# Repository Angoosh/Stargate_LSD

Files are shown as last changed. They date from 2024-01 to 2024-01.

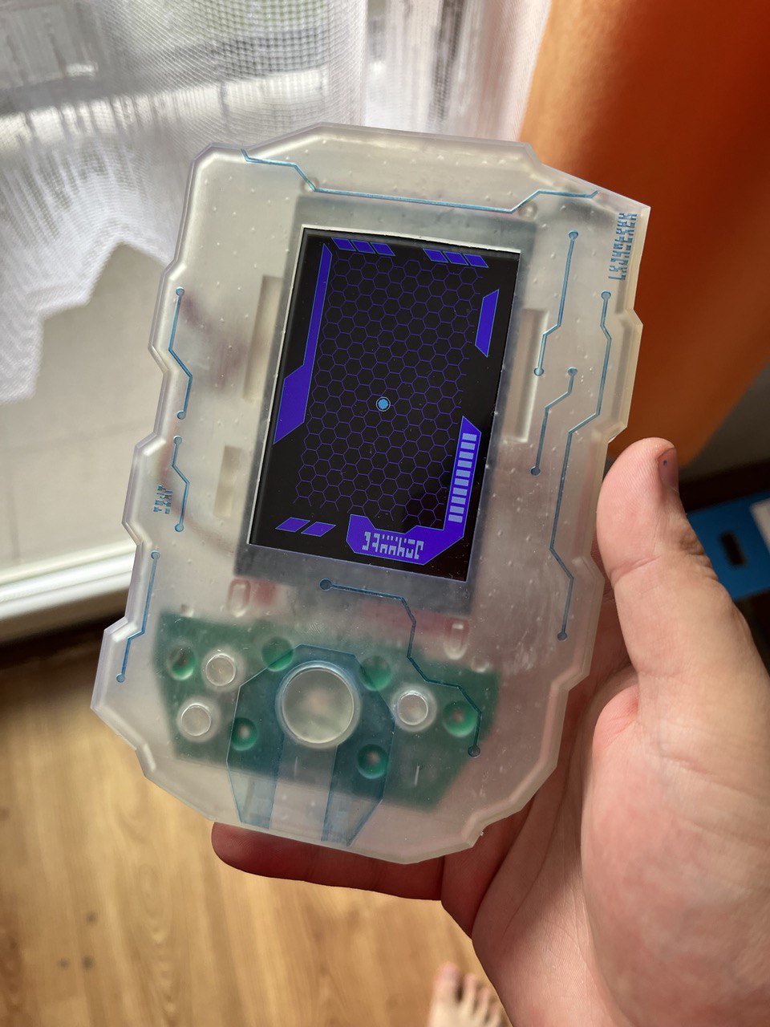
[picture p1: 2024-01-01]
image.jpg

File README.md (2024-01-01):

# Stargate_LSD
A Stargate Atlantis lifesigns detector prop design files and software. This is not a 1:1 prop replica, because I couldn't find screen which would match, but it is close enough. It was originally made as a reaction to one of my friends suggestions that we need a dork particle detector or as in our czech language kokoton detektor.

## Case printing and painting:
Case is printed out on a Elegoo Mars 2 Pro resin printer with Phrozen aqua clear resin. Painting is done with diluted transparent blue enamel paint and sanded over.

## Electronics:
Mainboard: [[https://github.com/LaskaKit/ESPD-35/tree/main]] but anything should fit with 3d model change. It is based on ESP32 because I wanted simplicity of arduino and wireless capabilities for future functions.<br>
Buttons use my custom PCB made with KiCAD.<br>
For sensors: SHT40 and VL53L0X are used.<br>
Optional other sensors and stuff can be programmed in and connected via pin header in the bottom of the device.

## Software:
It is a mess made on long nights over a 4 month period. It contains 3 modes in which it can operate:<br>
Dork particle detector, which uses the ToF sensor.<br
A temperature and humidity monitor.<br>
And as a life signs detector which is WIP and I don't know when it will be finished with all features. Right now it is just a simple blinking and beeping dot in the middle of the screen, but I have an idea to make it into a "real" life signs detector with an array of stationary beacons scattered around an area where it should detect stuff which will triangulate positions of the LSD and other mobile beacons and send that data into the LSD over MQTT or something like that. I don't know when I will have the time and mood to do that. Probably when the need arises for some LARP or something.

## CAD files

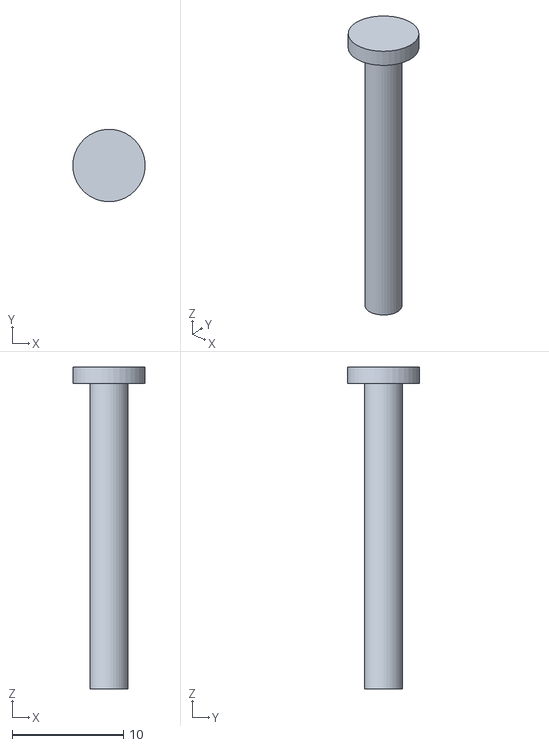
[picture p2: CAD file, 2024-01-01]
Hardware/3D print/power_button.STL
6.52 x 6.52 x 29.0

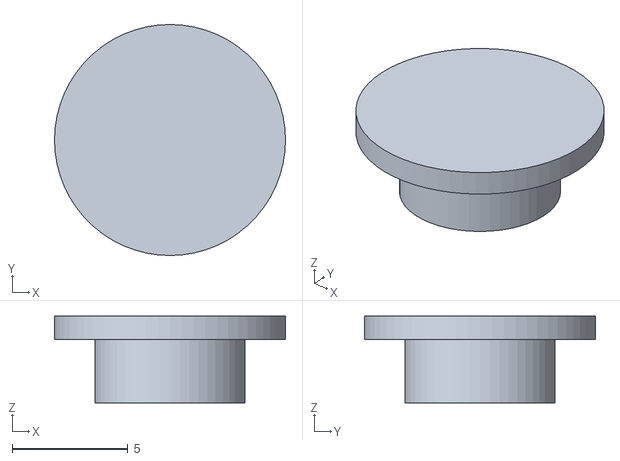
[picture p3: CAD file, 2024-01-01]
Hardware/3D print/tlacitko_male.STL
10.00 x 10.00 x 3.75

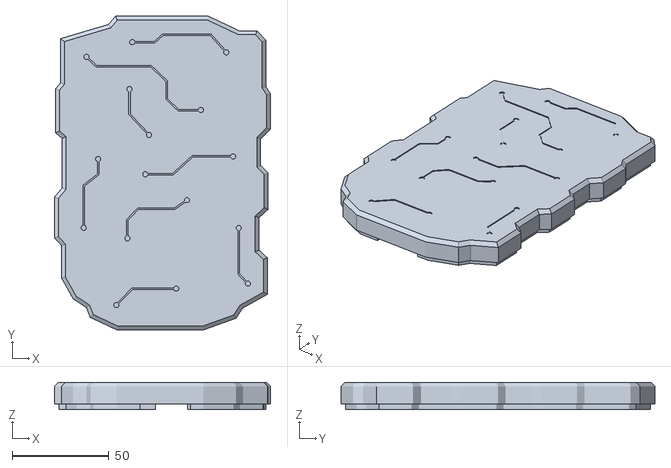
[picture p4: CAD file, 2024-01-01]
Hardware/3D print/Case_back.STL
111.4 x 161.9 x 14.0

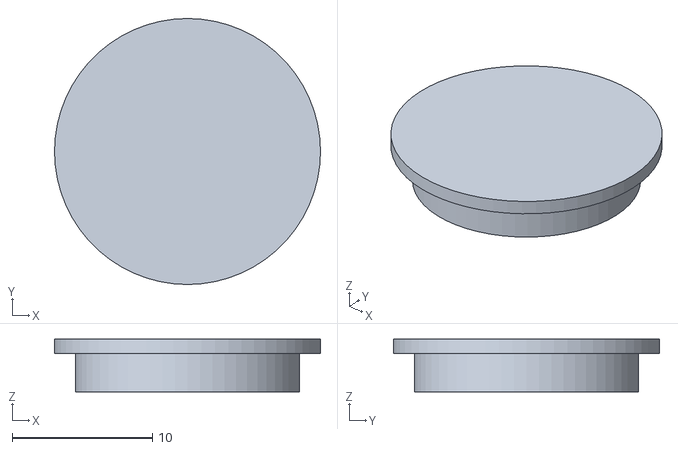
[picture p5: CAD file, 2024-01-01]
Hardware/3D print/tlacitko_velke.STL
19.0 x 19.0 x 3.75

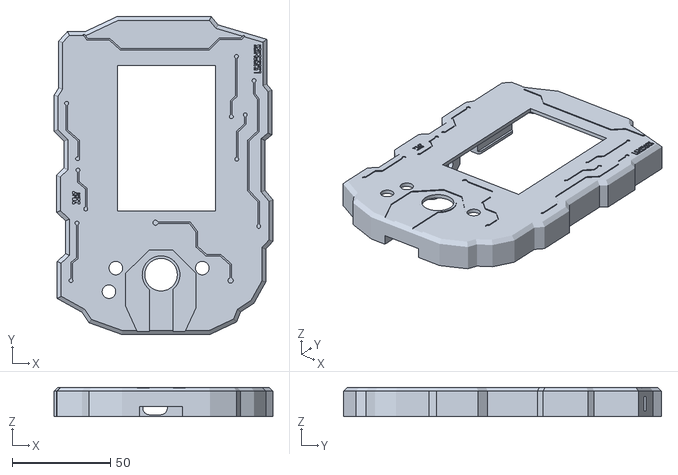
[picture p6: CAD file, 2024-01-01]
Hardware/3D print/Case_front.STL
111.4 x 161.9 x 15.0

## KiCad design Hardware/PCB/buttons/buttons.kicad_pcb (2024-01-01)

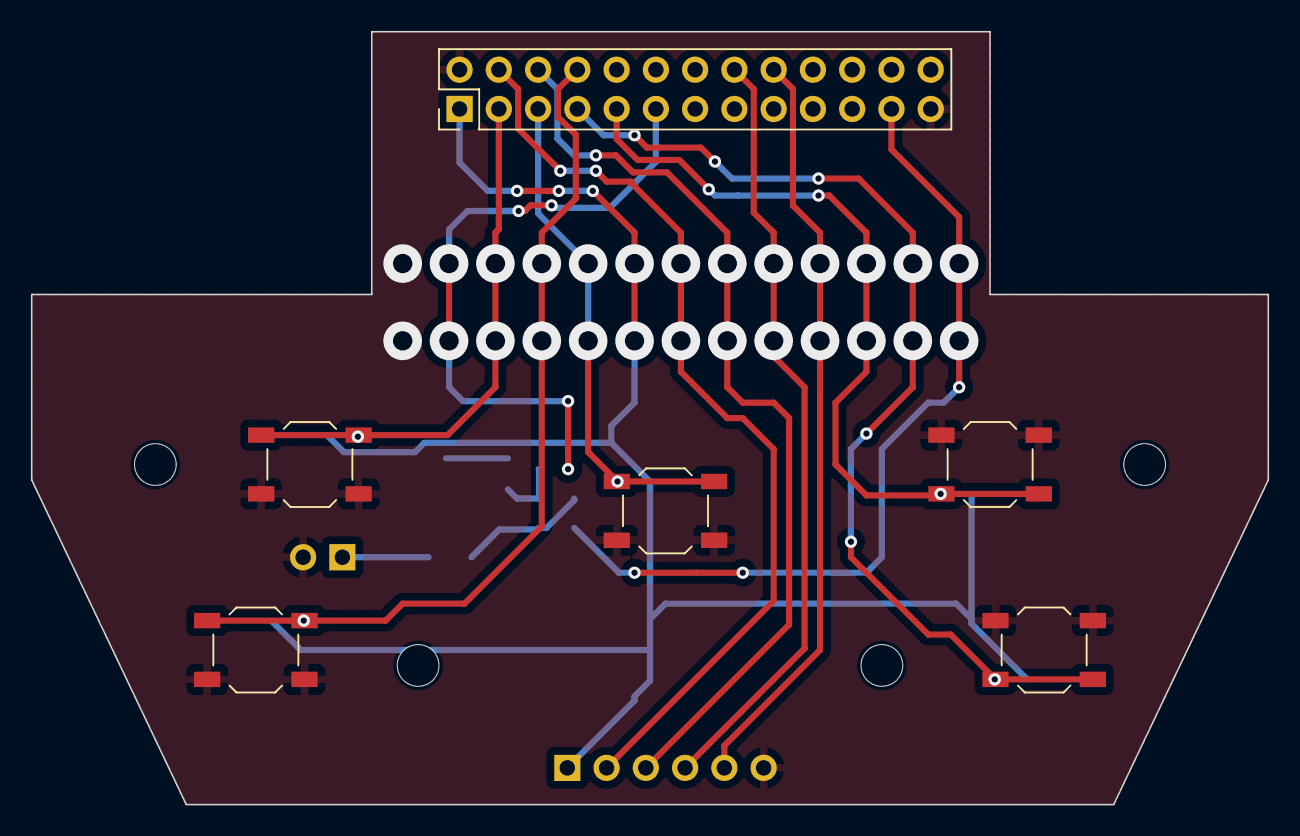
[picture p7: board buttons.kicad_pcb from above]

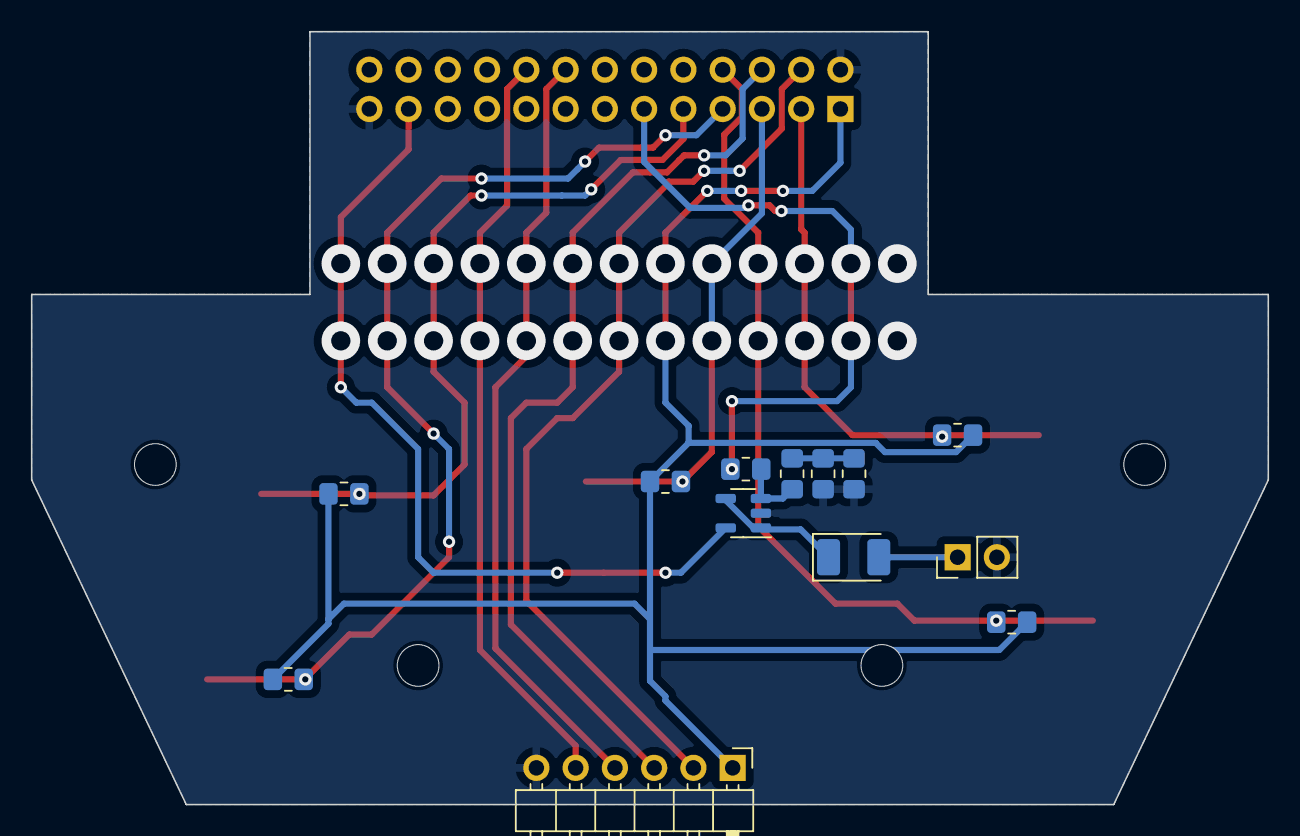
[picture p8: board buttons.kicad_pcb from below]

Board: 2 copper layers, 80.0 x 50.0 mm, 19 parts (13 on the bottom side), 17 nets.

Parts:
C1: 47u; CP_EIA-3528-21_Kemet-B_Pad1.50x2.35mm_HandSolder
J1: Conn_02x13_Odd_Even; PinHeader_2x13_P2.54mm_Vertical
J2: Conn_01x06; PinHeader_1x06_P2.54mm_Horizontal
LS1: Speaker; PinHeader_1x02_P2.54mm_Vertical
R1, R2, R3, R4: 10k; R_0805_2012Metric_Pad1.20x1.40mm_HandSolder
R5, R6, R7, R8, R9: 4k7; R_0805_2012Metric_Pad1.20x1.40mm_HandSolder
SW1, SW2, SW3, SW4, SW5: SW_Push; SW_SPST_TL3342
U1: AD8531ARTZ; SOT-23-5

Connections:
+3V3: J1.1, J2.1, R5.1, R6.1, R7.1, R8.1, R9.1
+BATT: J1.23, U1.5 (V+)
/SCL: J1.18, J2.5
/SDA: J1.16, J2.4
/SOUND: J1.11, R1.2
/SW_BACK: J1.7, R9.2, SW5.2
/SW_CENT: J1.5, R7.2, SW3.1
/SW_DWN: J1.8, R5.2, SW2.1
/SW_MENU: J1.9, R8.2, SW4.2
/SW_RX: J1.4, J2.2
/SW_TX: J1.6, J2.3
/SW_UP: J1.3, R6.2, SW1.1
GND: J1.2, J1.25, J2.6, LS1.2, R3.2, R4.2, SW1.2, SW2.2, SW3.2, SW4.1, SW5.1, U1.2 (V-)
unnamed: C1.2, LS1.1
unnamed: R2.2, R3.1, R4.1
unnamed: R1.1, R2.1, U1.3 (+)
unnamed: C1.1, U1.1, U1.4 (-)

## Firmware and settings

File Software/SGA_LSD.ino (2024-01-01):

#include <TFT_eSPI.h>            // Hardware-specific library
#include <SPI.h>
#include <Arduino.h>
#include <FS.h>
#include <ESP32AnalogRead.h>
#include "Wire.h"
#include "Adafruit_VL53L0X.h"
#include "Adafruit_SHT4x.h"
#include "SoundData.h"
#include "XT_DAC_Audio.h"

// TFT resolution
#define TFT_DISPLAY_RESOLUTION_X  320
#define TFT_DISPLAY_RESOLUTION_Y  480
#define CENTRE_Y                  TFT_DISPLAY_RESOLUTION_Y/2

// TFT SPI
#define TFT_LED          33      // TFT backlight pin
#define TFT_LED_PWM      100     // dutyCycle 0-255 last minimum was 15

// Buttons
#define BUTTON_UP        36
#define BUTTON_DOWN      16
//#define BUTTON_BACK      34
#define BUTTON_MENU      35
#define BUTTON_CENTER    39

//font
#define ALTERAN "stargate-alteran30"

#define TFT_GREY 0x7BEF
#define TFT_BG_COLOR 0xDA3E
#define TFT_POLY 0xC85D

//battery
#define BATTERY_ADC 34                      // Battery voltage mesurement
#define deviderRatio 1.7693877551  // Voltage devider ratio on ADC pin 1MOhm + 1.3MOhm

XT_Wav_Class Sound(kokoton_warning);
XT_Wav_Class Sound_beep(beep2);
XT_DAC_Audio_Class DacAudio(26,0);

ESP32AnalogRead adc;
TFT_eSPI tft = TFT_eSPI();       // Invoke custom library with default width and height
Adafruit_VL53L0X lox = Adafruit_VL53L0X();
Adafruit_SHT4x sht4 = Adafruit_SHT4x();

bool ToF_present = true;
bool SHT4x_present = true;

bool menu_changed = false;

void clear_work_window(){
  tft.fillRect(50, 24, 230, 386, TFT_BLACK);
}

void draw_background_1(){
  uint8_t hexagon_size = 14; //length of horizontal line in px
  int hex_pos_y = 36;
  for(int c = 0; c < 16; c++){
    for(int r = 0; r < 6; r++){
      int offset = (r + 1.2) * hexagon_size * 3;
      tft.drawLine(offset, (hex_pos_y - 12), (hexagon_size / 2) + offset, hex_pos_y, TFT_BG_COLOR);
      tft.drawLine(offset, (hex_pos_y + 12), (hexagon_size / 2) + offset, hex_pos_y, TFT_BG_COLOR);
      if(r < 5){
        tft.drawLine(offset + (hexagon_size / 2), hex_pos_y, hexagon_size + offset + (hexagon_size / 2), hex_pos_y, TFT_BG_COLOR);
        tft.drawLine(hexagon_size + offset + (hexagon_size / 2), hex_pos_y, (hexagon_size * 2) + offset, (hex_pos_y - 12), TFT_BG_COLOR);
        tft.drawLine(hexagon_size + offset + (hexagon_size / 2), hex_pos_y, (hexagon_size * 2) + offset, (hex_pos_y + 12), TFT_BG_COLOR);
        tft.drawLine((hexagon_size * 2) + offset, (hex_pos_y - 12), (hexagon_size * 3) + offset, (hex_pos_y - 12), TFT_BG_COLOR);
      }
      else{
        tft.drawLine(offset + (hexagon_size / 2), hex_pos_y, hexagon_size + offset, hex_pos_y, TFT_BG_COLOR);
      }
    }
    hex_pos_y += 24;
  }
}

void draw_life_sign(int x, int y, int create, int fade_level){//5 fade levels
  if(create){
    uint16_t color = 0;
    uint16_t grey_level = 0;
    switch(fade_level){
      case 0:
        color = 0x6bf;
        grey_level = 0xffff;
        break;
      case 1:
        color = 0x579;
        grey_level = 0xce59;
        break;
      case 2:
        color = 0x433;
        grey_level = 0x9cf3;
        break;
      case 3:
        color = 0x2ed;
        grey_level = 0x6b6d;
        break;
      case 4:
        color = 0x187;
        grey_level = 0x39e7;
        break;
      default:
        color = 0x6bf;
        grey_level = 0xffff;
        break;
    }
    tft.fillCircle(x, y, 7, color);
    tft.drawCircle(x, y, 10, grey_level);
  }
  else{
    tft.fillCircle(x, y, 7, TFT_BLACK);
    tft.drawCircle(x, y, 10, TFT_BLACK);
  }
}

int Battery_Get_Percent(float voltage){
  float map[21] = {4.2,4.15,4.11,4.08,4.02,3.98,3.95,3.91,3.87,3.85,3.84,3.82,3.8,3.79,3.77,3.75,3.73,3.71,3.69,3.61,3.27};

  for(int i = 0; i < 21; i++){
    if(voltage > map[i]){
      if(i == 0){
        return 100;
      }
      else{
        float delta = map[i - 1] - map[i];
        float voltage_step = delta / 5.0;
        float voltages[6] = {map[i], map[i] + voltage_step, map[i] + voltage_step * 2.0, map[i] + voltage_step * 3.0, map[i] + voltage_step * 4.0, map[i - 1]};
        int smallest_index = 0;

        for(int j = 0; j < 6; j++){
          if(voltage > voltages[j]){
            smallest_index = j;
          }
          else{
            break;
          }
        }

        return 100 - i*5 + smallest_index;
      }
    }
    else;
  }
  return 0;
}

int last_bars = 0;
void battery_status(uint8_t state){
  int rect_size = 9;
  bool refresh = false;
  
  float voltage = adc.readVoltage() * deviderRatio;
  int percent = Battery_Get_Percent(voltage);
  int bars = (percent / 10) + 0.5;
  
  if(last_bars != bars){
    refresh = true;
    last_bars = bars;
  }

  if(refresh){
    int polygon_points[12][2] = {
      {TFT_DISPLAY_RESOLUTION_X - 40, TFT_DISPLAY_RESOLUTION_Y / 2},
      {TFT_DISPLAY_RESOLUTION_X - 40, TFT_DISPLAY_RESOLUTION_Y - 70},
      {TFT_DISPLAY_RESOLUTION_X - 80, TFT_DISPLAY_RESOLUTION_Y - 70},
      {TFT_DISPLAY_RESOLUTION_X - 95, TFT_DISPLAY_RESOLUTION_Y - 55},
      {TFT_DISPLAY_RESOLUTION_X - 140, TFT_DISPLAY_RESOLUTION_Y - 55},
      {TFT_DISPLAY_RESOLUTION_X - 155, TFT_DISPLAY_RESOLUTION_Y - 70},
      {TFT_DISPLAY_RESOLUTION_X - 180, TFT_DISPLAY_RESOLUTION_Y - 70},
      {TFT_DISPLAY_RESOLUTION_X - 180, TFT_DISPLAY_RESOLUTION_Y - 30},
      {TFT_DISPLAY_RESOLUTION_X - 165, TFT_DISPLAY_RESOLUTION_Y - 15},
      {TFT_DISPLAY_RESOLUTION_X - 60, TFT_DISPLAY_RESOLUTION_Y - 15},
      {TFT_DISPLAY_RESOLUTION_X - 10, TFT_DISPLAY_RESOLUTION_Y - 65},
      {TFT_DISPLAY_RESOLUTION_X - 10, TFT_DISPLAY_RESOLUTION_Y / 2 + 20}
    };
    if(state == 0){
      tft.fillTriangle(polygon_points[0][0], polygon_points[0][1], polygon_points[1][0], polygon_points[1][1], polygon_points[11][0], polygon_points[11][1], TFT_POLY);
      tft.fillTriangle(polygon_points[11][0], polygon_points[11][1], polygon_points[10][0], polygon_points[10][1], polygon_points[1][0], polygon_points[1][1], TFT_POLY);
      tft.fillTriangle(polygon_points[10][0], polygon_points[10][1], polygon_points[1][0], polygon_points[1][1], polygon_points[9][0], polygon_points[9][1], TFT_POLY);
      tft.fillTriangle(polygon_points[2][0], polygon_points[2][1], polygon_points[1][0], polygon_points[1][1], polygon_points[9][0], polygon_points[9][1], TFT_POLY);
      tft.fillTriangle(polygon_points[2][0], polygon_points[2][1], polygon_points[3][0], polygon_points[3][1], polygon_points[9][0], polygon_points[9][1], TFT_POLY);
      tft.fillTriangle(polygon_points[3][0], polygon_points[3][1], polygon_points[9][0], polygon_points[9][1], polygon_points[8][0], polygon_points[8][1], TFT_POLY);
      tft.fillTriangle(polygon_points[4][0], polygon_points[4][1], polygon_points[3][0], polygon_points[3][1], polygon_points[8][0], polygon_points[8][1], TFT_POLY);
      tft.fillTriangle(polygon_points[4][0], polygon_points[4][1], polygon_points[5][0], polygon_points[5][1], polygon_points[8][0], polygon_points[8][1], TFT_POLY);
      tft.fillTriangle(polygon_points[5][0], polygon_points[5][1], polygon_points[7][0], polygon_points[7][1], polygon_points[8][0], polygon_points[8][1], TFT_POLY);
      tft.fillTriangle(polygon_points[5][0], polygon_points[5][1], polygon_points[7][0], polygon_points[7][1], polygon_points[6][0], polygon_points[6][1], TFT_POLY);
    }
    int bars_empty = 10 - bars;

    tft.fillRect(TFT_DISPLAY_RESOLUTION_X - 35, ((TFT_DISPLAY_RESOLUTION_Y / 2 + 25)), 20, 140, TFT_POLY);
    for(int i = 0; i < 10; i++){
      if(bars_empty == 0){
        tft.fillRect(TFT_DISPLAY_RESOLUTION_X - 35, ((TFT_DISPLAY_RESOLUTION_Y / 2 + 25) + (i * rect_size * 1.5)), 20, rect_size, TFT_WHITE);
      }
      else{
        tft.drawRect(TFT_DISPLAY_RESOLUTION_X - 35, ((TFT_DISPLAY_RESOLUTION_Y / 2 + 25) + (i * rect_size * 1.5)), 20, rect_size, TFT_WHITE);
        bars_empty --;
      }
    }
    if(state == 0){
      for(int i = 0; i < 12; i++){
        if(i < 11){
          tft.drawLine(polygon_points[i][0], polygon_points[i][1], polygon_points[i+1][0], polygon_points[i+1][1], TFT_CYAN);
        }
        else{
          tft.drawLine(polygon_points[i][0], polygon_points[i][1], polygon_points[0][0], polygon_points[0][1], TFT_CYAN);
        }
      }
  
      tft.loadFont(ALTERAN);
      tft.setCursor(TFT_DISPLAY_RESOLUTION_X - 155, TFT_DISPLAY_RESOLUTION_Y - 48);
      tft.setTextColor(TFT_WHITE,TFT_BLACK);
      tft.print("BATTERY");
    }
  }
}

void draw_cosmetic_graphics(){
  int n_o_diamonds = 9;
  int points[n_o_diamonds][4][2] = {
    {{120,430},{90,430},{70,450},{100,450}},
    {{80,430},{50,430},{30,450},{60,450}},
    {{280,20},{255,20},{240,5},{265,5}},
    {{250,20},{225,20},{210,5},{235,5}},
    {{220,20},{195,20},{180,5},{205,5}},
    {{80,20},{55,20},{40,5},{65,5}},
    {{110,20},{85,20},{70,5},{95,5}},
    {{140,20},{115,20},{100,5},{125,5}},
    {{300,150},{280,135},{280,65},{300,50}},
  };

  int polygon[6][2] = {
    {45,30},{30,15},{30,200},{5,225},{5,325},{45,285}
  };

  tft.fillTriangle(polygon[0][0], polygon[0][1], polygon[1][0], polygon[1][1], polygon[2][0], polygon[2][1], TFT_POLY);
  tft.fillTriangle(polygon[0][0], polygon[0][1], polygon[5][0], polygon[5][1], polygon[2][0], polygon[2][1], TFT_POLY);
  tft.fillTriangle(polygon[2][0], polygon[2][1], polygon[5][0], polygon[5][1], polygon[4][0], polygon[4][1], TFT_POLY);
  tft.fillTriangle(polygon[3][0], polygon[3][1], polygon[2][0], polygon[2][1], polygon[4][0], polygon[4][1], TFT_POLY);
  for(int i = 0; i < 6; i++){
    if(i < 5){
      tft.drawLine(polygon[i][0], polygon[i][1], polygon[i+1][0], polygon[i+1][1], TFT_CYAN);
    }
    else{
      tft.drawLine(polygon[i][0], polygon[i][1], polygon[0][0], polygon[0][1], TFT_CYAN);
    }
  }

  for(int s = 0; s < n_o_diamonds; s++){
    tft.fillTriangle(points[s][0][0], points[s][0][1], points[s][1][0], points[s][1][1], points[s][2][0], points[s][2][1], TFT_POLY);
    tft.fillTriangle(points[s][0][0], points[s][0][1], points[s][2][0], points[s][2][1], points[s][3][0], points[s][3][1], TFT_POLY);
    for(int i = 0; i < 4; i++){
      if(i < 3){
        tft.drawLine(points[s][i][0], points[s][i][1], points[s][i+1][0], points[s][i+1][1], TFT_CYAN);
      }
      else{
        tft.drawLine(points[s][i][0], points[s][i][1], points[s][0][0], points[s][0][1], TFT_CYAN);
      }
    }
  }
}

int last_measurement = 0;
int ToF_read(){
  if(ToF_present){
    VL53L0X_RangingMeasurementData_t measure;
    lox.rangingTest(&measure, false);
    if (measure.RangeStatus != 4) {
      last_measurement = measure.RangeMilliMeter;
      return measure.RangeMilliMeter;
    }
    else{
      return -1;
    }
  }
  else{
    return -2;
  }
}

void SHT4x_read(float *retvals){
  if(SHT4x_present){
    sensors_event_t humidity, temp;
    sht4.getEvent(&humidity, &temp);
    retvals[0] = temp.temperature;
    retvals[1] = humidity.relative_humidity;
  }
  else{
    retvals[0] = 0;
    retvals[1] = 0;
  }
}

int env_data[2], env_data_old[2];
void teplotaVlhkost(){
  float tmp_env_data[2];
  bool refresh = false;
  SHT4x_read(tmp_env_data);
  env_data[0] = (int)tmp_env_data[0];
  env_data[1] = (int)tmp_env_data[1];
  if((env_data[0] != env_data_old[0]) || (env_data[1] != env_data_old[1])){
    refresh = true;
  }
  if(menu_changed){
    menu_changed = false;
    refresh = true;
    draw_background_1();
    tft.setCursor(50, 30);
    tft.print("teplota");
    tft.setCursor(50, 60);
    tft.print("vlhkost");
  }
  
  if(refresh){
    tft.setTextColor(TFT_BLACK,TFT_BLACK);
    tft.setCursor(150, 30);
    tft.print(env_data_old[0]);
    tft.setCursor(150, 60);
    tft.print(env_data_old[1]);
    tft.setTextColor(TFT_WHITE,TFT_BLACK);
    tft.setCursor(150, 30);
    tft.print(env_data[0]);
    tft.setCursor(150, 60);
    tft.print(env_data[1]);

    env_data_old[0] = env_data[0];
    env_data_old[1] = env_data[1];
  }
}

int kokoton_state = -1;
int koncentrace_old = 0;
int koncentrace_pure_old = 0;

void kokotonDetector(){
  int kokoton_distance = ToF_read();
  int x = TFT_DISPLAY_RESOLUTION_X / 2;
  int y = TFT_DISPLAY_RESOLUTION_Y / 2;
  bool refresh = false;

  if(menu_changed){
    menu_changed = false;
    refresh = true;
  }
  //Serial.println(kokoton_distance);

  if(kokoton_distance == -2){
    kokoton_state = -1;
    return;
  }
  if(kokoton_distance == -1){
    if(kokoton_state != 0){
      refresh = true;
    }
    kokoton_state = 0;
  }
  else if(kokoton_distance < 200){
    if(kokoton_state != 3){
      refresh = true;
    }
    kokoton_state = 3;
  }
  else if(kokoton_distance < 400){
    if(kokoton_state != 2){
      refresh = true;
    }
    kokoton_state = 2;
  }
  else if(kokoton_distance < 600){
    if(kokoton_state != 1){
      refresh = true;
    }
    kokoton_state = 1;
  }
  else{
    if(kokoton_state != 0){
      refresh = true;
    }
    kokoton_state = 0;
  }

  int koncentrace = (int)((8196.0-(float)kokoton_distance)/20.0);
  int koncentrace_pure = 8196-last_measurement;
  if(koncentrace != koncentrace_old){
    tft.setCursor(50, 90);
    tft.setTextColor(TFT_BLACK,TFT_BLACK);
    tft.print(koncentrace_pure_old);
    tft.setCursor(50, 90);
    tft.setTextColor(TFT_WHITE,TFT_BLACK);
    tft.print(koncentrace_pure);
    koncentrace_old = koncentrace;
    koncentrace_pure_old = koncentrace_pure;
  }

  if(refresh){
    clear_work_window();
    draw_background_1();
    tft.setCursor(50, 30);
    tft.print("kokotony");
    tft.setCursor(50, 60);
    tft.print("koncentrace ");
    int koncentrace = 8196-kokoton_distance;
    tft.setCursor(50, 90);
    tft.print(koncentrace);
    
    if(kokoton_state >= 1){
      tft.drawTriangle(x, y-21, x+25, y-64, x-25, y-64, TFT_WHITE);
      tft.fillTriangle(x, y-27, x+19, y-61, x-19, y-61, TFT_CYAN);
    }
    if(kokoton_state >= 2){
      tft.drawTriangle(x-19, y+10, x-69, y+10, x-44, y+54, TFT_WHITE);
      tft.fillTriangle(x-25, y+13, x-63, y+13, x-44, y+48, TFT_CYAN);
    }
    if(kokoton_state == 3){
      tft.drawTriangle(x+19, y+10, x+69, y+10, x+44, y+54, TFT_WHITE);
      tft.fillTriangle(x+25, y+13, x+63, y+13, x+44, y+48, TFT_CYAN);
    }
    refresh = false;
  }
  
  tft.fillCircle(x, y, 15, TFT_CYAN);
  tft.drawCircle(x, y, 18, TFT_WHITE);

  if(kokoton_state == 3){
    int i = 1;
    while(i != 0){
      DacAudio.FillBuffer();
      if(Sound.Playing == false){
        DacAudio.Play(&Sound);
        i --;
      }
    }
  }
}

int readButtons(){
  int buttonState = 0;
  buttonState = !digitalRead(BUTTON_UP);
  buttonState += (!digitalRead(BUTTON_DOWN) << 1);
//  buttonState += !(digitalRead(BUTTON_BACK) << 2);
  buttonState += (!digitalRead(BUTTON_MENU) << 3);
  buttonState += (!digitalRead(BUTTON_CENTER) << 4);

  return buttonState;
}

int menu_items = 3;
void menuGraphics(){
  int start_pixel[2] = {53, 33};
  int rect_size[2] = {150, 40};
  int rect_spacing = 4;
  int text_offset[2] = {3, 6};
  String menu_items_names[menu_items] = {"kokotony", "temphum", "lifesigns"};

  for(int i = 0; i < menu_items; i++){
    tft.fillRect(start_pixel[0], start_pixel[1]+(rect_spacing+2+rect_size[1])*i, rect_size[0], rect_size[1], TFT_GREY);
    tft.drawRect(start_pixel[0]-1, (start_pixel[1]-1)+(rect_spacing+rect_size[1]+2)*i, rect_size[0]+2, rect_size[1]+2, TFT_CYAN);
    tft.setCursor(start_pixel[0]+text_offset[0], start_pixel[1]+text_offset[1]+(rect_spacing+rect_size[1]+2)*i);
    tft.print(menu_items_names[i]);
  }
}

void menuSelectGraphics(int pos){
  int start_pixel[2] = {53, 33};
  int rect_size[2] = {150, 40};
  int rect_spacing = 4;

  for(int i = 0; i < menu_items; i++){
    if(i == pos){
      tft.drawRect(start_pixel[0]-2, (start_pixel[1]-2)+(rect_spacing+rect_size[1]+2)*i, rect_size[0]+4, rect_size[1]+4, TFT_WHITE);
      tft.drawRect(start_pixel[0]-3, (start_pixel[1]-3)+(rect_spacing+rect_size[1]+2)*i, rect_size[0]+6, rect_size[1]+6, TFT_WHITE);
    }
    else{
      tft.drawRect(start_pixel[0]-2, (start_pixel[1]-2)+(rect_spacing+rect_size[1]+2)*i, rect_size[0]+4, rect_size[1]+4, TFT_BLACK);
      tft.drawRect(start_pixel[0]-3, (start_pixel[1]-3)+(rect_spacing+rect_size[1]+2)*i, rect_size[0]+6, rect_size[1]+6, TFT_BLACK);
    }
  }
}

int menu_pos = 0;
int menu_pos_draw = 0;
bool menu_open = false;
void menuSelect(){//1 = up 2 = down
  if(!menu_open){
    clear_work_window();
    menuGraphics();
    menuSelectGraphics(menu_pos_draw);
    menu_pos = menu_pos_draw;
    menu_open = true;
  }
  int buttonNum = 0;
  int buttonNumOld = 0;
  while(menu_open){
    delay(100);
    buttonNum = readButtons();
    if(buttonNum != buttonNumOld){
      buttonNumOld = buttonNum;
      if(buttonNum == 8){//menu button closes menu
        menu_open = false;
        menu_changed = true;
        clear_work_window();
      }
      if(buttonNum == 1){
        menu_pos --;
        if(menu_pos < 0){
          menu_pos = menu_items-1;
        }
        menuSelectGraphics(menu_pos);
      }
      if(buttonNum == 2){
        menu_pos ++;
        if(menu_pos > menu_items-1){
          menu_pos = 0;
        }
        menuSelectGraphics(menu_pos);
      }
      if(buttonNum == 16){
        menu_pos_draw = menu_pos;
        menu_open = false;
        menu_changed = true;
        clear_work_window();
      }
    }
  }
}

uint32_t last_time_lifesign_ran = 0;
uint8_t lifesign_fadelevel = 4;
uint8_t lifesign_fade_dir = 0;

void lifeSigns(){
  bool refresh = false;
  
  if(menu_changed){
    menu_changed = false;
    refresh = true;
    draw_background_1();
  }
  if(millis() > (last_time_lifesign_ran + 200)){
    refresh = true;
    last_time_lifesign_ran = millis();
  }
  if(refresh){
    draw_life_sign(TFT_DISPLAY_RESOLUTION_X / 2, TFT_DISPLAY_RESOLUTION_Y / 2, 1, lifesign_fadelevel);
    if(lifesign_fade_dir == 0){
      lifesign_fadelevel --;
    }
    else{
      lifesign_fadelevel ++;
    }
    if(lifesign_fadelevel == 4){
      lifesign_fade_dir = 0;
    }
    if(lifesign_fadelevel == 0){
      lifesign_fade_dir = 1;
      int i = 1;
      while(i != 0){
        DacAudio.FillBuffer();
        if(Sound.Playing == false){
          DacAudio.Play(&Sound_beep);
          i --;
        }
      }
    }
  }
}

void setup() {
  Serial.begin(115200);
  // put your setup code here, to run once:
  Wire.begin();
  adc.attach(BATTERY_ADC);
  
  ledcSetup(1, 5000, 8);              // ledChannel, freq, resolution
  ledcAttachPin(TFT_LED, 1);          // ledPin, ledChannel
  ledcWrite(1, TFT_LED_PWM);          // dutyCycle 0-255

  //Buttons
  pinMode(BUTTON_UP, INPUT);
  pinMode(BUTTON_DOWN, INPUT_PULLUP);
 // pinMode(BUTTON_BACK, INPUT);
  pinMode(BUTTON_MENU, INPUT);
  pinMode(BUTTON_CENTER, INPUT);

  if (!lox.begin()) {
    ToF_present = false;
  }
  if (! sht4.begin()) {
    SHT4x_present = false;
  }
  else{
    sht4.setPrecision(SHT4X_HIGH_PRECISION);
    sht4.setHeater(SHT4X_NO_HEATER);
  }

  // Setup the LCD
  tft.init();
  tft.setRotation(2);
  tft.fillScreen(TFT_BLACK);

  if (!SPIFFS.begin()) {
    Serial.println("SPIFFS initialisation failed!");
    while (1) yield(); // Stay here twiddling thumbs waiting
  }
  Serial.println("\r\nSPIFFS available!");

  // ESP32 will crash if any of the fonts are missing
  bool font_missing = false;
  if (SPIFFS.exists("/stargate-alteran30.vlw")    == false) font_missing = true;

  if (font_missing)
  {
    Serial.println("\r\nFont missing in SPIFFS, did you upload it?");
    while(1) yield();
  }
  else Serial.println("\r\nFonts found OK.");

  draw_background_1();
  draw_cosmetic_graphics();

  battery_status(0);

  tft.setTextColor(TFT_WHITE,TFT_BLACK);
  tft.loadFont(ALTERAN); // Must load the font first
  
/*  for(int i = 0; i < 30; i++){
    draw_life_sign(120 + i*3, 200 + i*5, 1);
    tft.setCursor(20, 20); // Set cursor at top left of screen
    tft.println("WHOAREYOU"); // println moves cursor down for a new line
    delay(500);
    draw_life_sign(120 + i*3, 200 + i*5, 0);
    draw_background();
  }*/
//  tft.setCursor(50, 60);
//  tft.print("uptime");

  menuSelect();
}

int uptime = 0;
void loop() {
  // put your main code here, to run repeatedly:
  battery_status(1);
 
  if(readButtons() == 8){
    menuSelect();
  }
  switch(menu_pos_draw){
    case 0:
      kokotonDetector();
      break;
    case 1:
      teplotaVlhkost();
      break;
    case 2:
      lifeSigns();
      break;
    default:
      kokotonDetector();
      break;
  }

  delay(10);
}

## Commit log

2024-01-01 initial batch commit
    [Case_back.STL, Case_front.STL, power_button.STL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]
2024-01-01 hardware, function and software description added to readme and kicad files aded
    [Case_back.STL, Case_front.STL, buttons.kicad_pcb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]
